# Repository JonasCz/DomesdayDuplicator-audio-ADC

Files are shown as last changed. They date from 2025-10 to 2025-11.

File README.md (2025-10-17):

# An experiment to add an audio ADC to the Domesday Duplicator (DdD)

An extension to the DdD to to add synced baseband audio support, with the DdD capture app writing it as a separate WAV file. Both PCM1802 (common module from china or custom board), or using the built-in adc128s102 that is already integrated on the DE0-nano board. PCM1802 has better quality, integrated ADC notably has a high noise floor at -40dB.

## Setup:

### You can use either:

**Custom board**: I designed a custom board, which has RCAs for both the PCM 1802, and the integrated adc128s102, allowing to use 4 channels at the same time if desired. Has better power regulator than PCM1802 modules (maybe lower noise), has a DIP switch for -10dB input level if needed.

This currently has some errors, notably the connectior is flipped so it doesn't fit as intended, and requires one small bodge for the dout output buffer (output enable needs to be low, not high). I have a few spare (pre-bodged and soldered, with RCAs once they arrive), contact @Doohickey in Domesday86 discord, for around €15 + cheap shipping in europe. I'll maybe make a fixed version later.

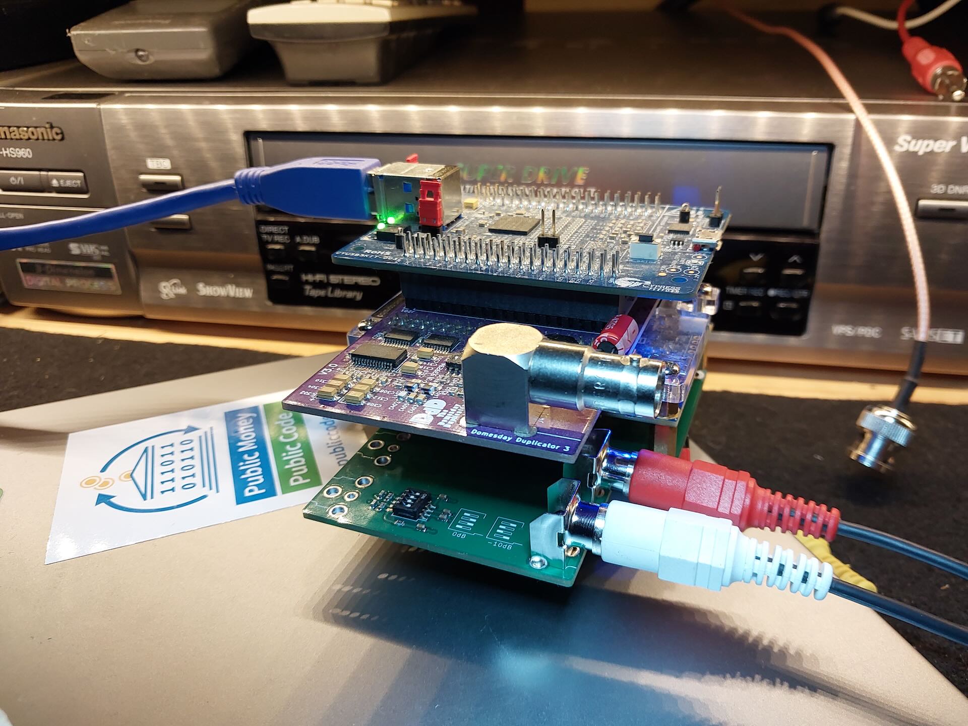
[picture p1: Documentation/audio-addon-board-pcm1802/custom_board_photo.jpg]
custom board photo


**PCM1802 module**:

You can also use the low cost PCM1802 module. Connect with jumper wires, diagram:

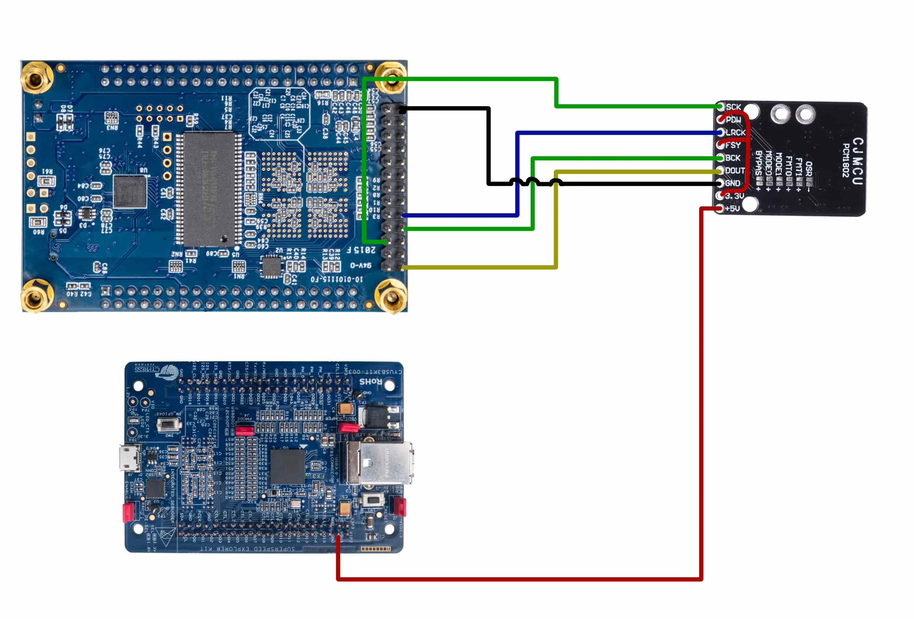
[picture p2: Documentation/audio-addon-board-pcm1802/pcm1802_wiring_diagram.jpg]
PCM1802 module connection diagram


Wires between pcm1802 and DdD should be as short as possible. You don't need to solder any of the fmt/mode/osr/bypass. Make sure the 3.3v on your module is working (3.3v is present), 3.3v needs to be connected to the pdw and fsy pins on the module. Connect lin/rin/gnd on the module to your audio source.

**adc128s102**:

Can be used with just some resistors and capacitors:

Resistors: any value between 1k and 10k works. Capacitor 1-10uF works. All capacitors and resistors need to be the same.

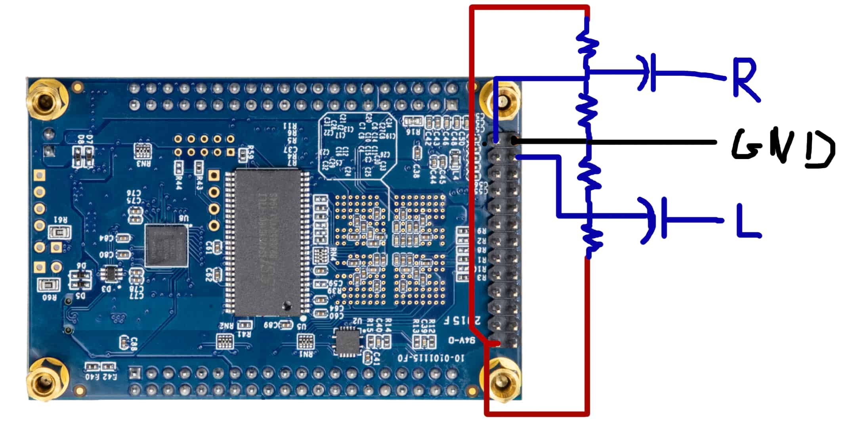
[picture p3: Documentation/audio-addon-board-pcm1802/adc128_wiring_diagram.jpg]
adc128s102


Can be used together with PCM1802 for 4 channels.

## Firmware:

You'll need to flash the firmware of the deo-nano, using the same process as for the initial flash. (firmware file in releases section). Note that there's no backward compatiblity, both the firmware and application need to be from this repository. Firmware from this repository won't work with old application either.

## Application:

Set your audio source in the application settings, then start capturing. It will write a wav file in the same location as the RF data, and show some statistics for the audio. The application is missing the logo in the UI because I couldn't get it to work, it's not intentionally removed :-)

(original readme follows)

# Domesday Duplicator (DdD)

Please see the [Project Wiki](https://github.com/simoninns/DomesdayDuplicator/wiki) for details of the project and for access to the project documentation.



The Domesday Duplicator is a LaserDisc capture focused, USB 3.0 based DAQ capable of 40 million samples per second acquisition of analogue RF data at 10-bits resolution, the data being in generic PCM style stream format is ready for [FLAC compression](https://github.com/oyvindln/vhs-decode/wiki/RF-Compression-&-Decompression-Guide) or direct use with a wide range of decoders.

Capture is via a easy to use GUI capture application.



# The Decode Family 

The samples the DdD capture can be used with the family of decoders that make the FM RF Archival workflow ready to use today.

[LaserDisc Decode](https://github.com/happycube/ld-decode) / [VHS-Decode (Videotape)](https://github.com/oyvindln/vhs-decode/wiki/) / [CVBS (Composite) Decode](CVBS-Composite-Decode) / [HiFi Decode](HiFi-Decode) / [RTLSDR HiFi Decode](RTLSDR) / [MUSE-Decode](https://bitbucket.org/staffanulfberg/ldaudio/src/master/musecpp/) / [CD-Decode](https://github.com/happycube/cd-decode) / [FL2K TBC Player](TBC-To-Analogue)

# 3D Printed Case 

The DomesDay Duplicator also has a [3D models](https://github.com/simoninns/DomesdayDuplicator-Case) and ready to use data for producing 3D printed cases, to protect from dust or line with copper tape for affordable EMI shielding for example.



## Authors

Domesday Duplicator was written & designed by [Simon Inns](https://github.com/simoninns).

Current documentation & fabrication is maintained by [Harry Munday](https://github.com/harrypm). 

## Licences

- [Software License - (Creative Commons BY-SA 4.0)](https://github.com/simoninns/DomesdayDuplicator/blob/master/LICENSE)
- [Hardware License - (GPLv3)](https://creativecommons.org/licenses/by-sa/4.0/)

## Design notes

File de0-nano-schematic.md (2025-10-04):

Of course, here is a detailed description of the Terasic DE0-Nano board's schematics, with a breakdown of each component, its pins, and their connections. 

 ### **1. Main Components and System Overview** 

 The Terasic DE0-Nano is a compact development board centered around an Altera Cyclone IV EP4CE22F17C6N FPGA. The board is designed for a wide array of applications, from educational purposes to embedded systems development. Key components on the board include: 

 *   **FPGA:** Altera Cyclone IV EP4CE22F17C6N with 22,320 logic elements. 
 *   **SDRAM:** 32MB of SDRAM for data storage. 
 *   **A/D Converter:** An 8-channel, 12-bit Analog-to-Digital Converter. 
 *   **Accelerometer:** A 3-axis digital accelerometer. 
 *   **I/O:** User LEDs, push-buttons, DIP switches, and expansion headers. 

 ### **2. Component Details and Pin Connections** 

 Below is a comprehensive list of the components, their pin names, numbers, and their connections as depicted in the schematics. 

 #### **2.1. Altera Cyclone IV FPGA (U1)** 

 The heart of the DE0-Nano board is the Cyclone IV FPGA. The following sections detail the pin connections for the various banks of the FPGA. 

 **Bank 1:** 
 *   **Pin B1 (DQS2L/CQ3L,CDPCLK0):** Connected to LED6. 
 *   **Pin C2 (DIFFIO_L3p):** Connected to DRAM_WE_N. 
 *   **Pin D1 (DIFFIO_L3n):** Connected to LED4. 
 *   **Pin F2 (DIFFIO_L4n):** Connected to I2C_SCLK. 
 *   **Pin F1 (DIFFIO_L5p):** Connected to I2C_SDAT. 
 *   **Pin G2 (DIFFIO_L5n):** Connected to DRAM_DQ0. 
 *   **Pin G1 (DIFFIO_L6p/DQS0L/CQ1L,DPCLK0):** Connected to DRAM_DQ1. 
 *   **Pin G5 (IO1_0):** Connected to G_SENSOR_CS_N. 
 *   **Pin F3 (IO/VREFB1N0):** Connected to LED5. 
 *   **Pin E1 (CLK1/DIFFCLK_0n):** Connected to KEY1. 

 **Bank 2:** 
 *   **Pin L4 (RUP1/DQ1L):** Connected to DRAM_ADDR8. 
 *   **Pin K5 (RDN1/DQ1L):** Connected to DRAM_DQ3. 
 *   **Pin R1 (IO/VREFB2N0):** Connected to DRAM_ADDR12. 
 *   **Pin L3 (CLK3/DIFFCLK_1n):** Connected to LED7 and G_SENSOR_INT. 

 **Bank 3:** 
 *   **Pin N3 (DIFFIO_B1p):** Connected to DRAM_DQ14. 
 *   **Pin P3 (DIFFIO_B1n/DM3B/BWS#3B):** Connected to DRAM_DQ13. 
 *   **Pin R3 (DIFFIO_B2p/DQ3B):** Connected to DRAM_DQ11. 
 *   **Pin T3 (DIFFIO_B2n):** Connected to DRAM_DQ10. 
 *   **Pin N5 (DIFFIO_B4p/DQ3B):** Connected to DRAM_ADDR1. 
 *   **Pin N6 (DIFFIO_B4n/DQ3B):** Connected to DRAM_ADDR2. 
 *   **Pin M7 (DIFFIO_B5p/DQS3B/CQ3B#,DPCLK2):** Connected to DRAM_BA0. 
 *   **Pin R5 (DIFFIO_B5n/DQ3B):** Connected to DRAM_DQ12. 
 *   **Pin T5 (DIFFIO_B6p/DQ3B):** Connected to DRAM_DQM1. 
 *   **Pin R6 (DIFFIO_B6n):** Connected to DRAM_DQM0. 
 *   **Pin T6 (DIFFIO_B7p/DQ3B):** Connected to DRAM_ADDR7. 
 *   **Pin R7 (DIFFIO_B7n):** Connected to DRAM_DQ7. 
 *   **Pin T7 (DIFFIO_B8p/DQ3B):** Connected to DRAM_ADDR5. 
 *   **Pin L8 (DIFFIO_B8n/DQS5B/CQ5B#,DPCLK3):** Connected to DRAM_DQ2. 
 *   **Pin M8 (DIFFIO_B9n/DQ3B):** Connected to DRAM_ADDR3. 
 *   **Pin N8 (DIFFIO_B10n/DM5B/BWS#5B):** Connected to DRAM_ADDR6. 
 *   **Pin P8 (DIFFIO_B11p/DQ5B):** Connected to DRAM_ADDR4. 
 *   **Pin T2 (IO3_0/DQS1B/CQ1B#,CDPCLK2):** Connected to DRAM_DQ9. 
 *   **Pin M6 (IO3_1/DQ3B):** Connected to DRAM_BA1. 
 *   **Pin L7 (IO3_2/DQ3B):** Connected to DRAM_CKE. 
 *   **Pin P6 (IO/VREFB3N0):** Connected to DRAM_CS_N. 
 *   **Pin R4 (PLL1_CLKOUTp):** Connected to DRAM_CLK. 
 *   **Pin T4 (PLL1_CLKOUTn):** Connected to DRAM_DQ8. 
 *   **Pin R8 (CLK15/DIFFCLK_6p):** Connected to CLOCK_50. 
 *   **Pin T8 (CLK14/DIFFCLK_6n):** Connected to SW1. 

 **Bank 4:** 
 *   **Pin N9 (DIFFIO_B14n/DQ5B):** Connected to GPIO_114. 
 *   **Pin R10 (DIFFIO_B16p/DQ5B):** Connected to GPIO_111. 
 *   **Pin T10 (DIFFIO_B16n/DQS4B/CQ5B,DPCLK4):** Connected to GPIO_18. 
 *   **Pin R11 (DIFFIO_B17p/DQ5B):** Connected to GPIO_19. 
 *   **Pin T11 (DIFFIO_B17n):** Connected to GPIO_17. 
 *   **Pin R12 (DIFFIO_B18p/DQ5B):** Connected to GPIO_16. 
 *   **Pin T12 (DIFFIO_B18n/DQ5B):** Connected to GPIO_15. 
 *   **Pin R13 (DIFFIO_B20p):** Connected to GPIO_14. 
 *   **Pin T13 (DIFFIO_B20n/DQ5B):** Connected to GPIO_13. 
 *   **Pin T14 (DIFFIO_B23p/DQ5B):** Connected to GPIO_12. 
 *   **Pin T15 (DIFFIO_B23n/DQS0B/CQ1B,CDPCLK3):** Connected to GPIO_11. 
 *   **Pin N12 (DIFFIO_B24p):** Connected to GPIO_112. 
 *   **Pin P9 (IO4_0/DQS2B/CQ3B,DPCLK5):** Connected to GPIO_113. 
 *   **Pin M10 (RUP2):** Connected to GPIO_128. 
 *   **Pin N11 (RDN2):** Connected to GPIO_115. 
 *   **Pin P11 (IO/VREFB4N0):** Connected to GPIO_110. 
 *   **Pin P14 (PLL4_CLKOUTp):** Connected to GPIO_125. 
 *   **Pin R14 (PLL4_CLKOUTn):** Connected to GPIO_122. 
 *   **Pin R9 (CLK13/DIFFCLK_7p):** Connected to GPIO_1_IN1. 
 *   **Pin T9 (CLK12/DIFFCLK_7n):** Connected to GPIO_1_IN0. 

 **Bank 5:** 
 *   **Pin P16 (DIFFIO_R15n/DQS3R/CQ3R#,CDPCLK4):** Connected to GPIO_121. 
 *   **Pin R16 (DIFFIO_R15p/DQ1R):** Connected to GPIO_118. 
 *   **Pin N16 (DIFFIO_R13n/DQ1R):** Connected to GPIO_123. 
 *   **Pin N15 (DIFFIO_R13p/DQ1R):** Connected to GPIO_124. 
 *   **Pin L13 (DIFFIO_R12p/DQ1R):** Connected to GPIO_129. 
 *   **Pin L16 (DIFFIO_R11n/DQ1R):** Connected to GPIO_116. 
 *   **Pin L15 (DIFFIO_R11p):** Connected to GPIO_119. 
 *   **Pin K16 (RUP3/DM1R/BWS#1R):** Connected to GPIO_117. 
 *   **Pin K15 (DIFFIO_R10n/DQ1R):** Connected to GPIO_131. 
 *   **Pin J16 (DIFFIO_R10p/DQS1R/CQ1R#,DRCLK6):** Connected to KEY0. 
 *   **Pin J15 (DIFFIO_R9n/DEV_OE):** Connected to GPIO_130. 
 *   **Pin J14 (DIFFIO_R9p/DEV_CLRn):** Connected to GPIO_133. 
 *   **Pin J13 (DIFFIO_R8n/DQ1R):** Connected to GPIO_132. 
 *   **Pin N14 (RDN3/DQ1R):** Connected to GPIO_127. 
 *   **Pin P15 (IO/VREFB5N0):** Connected to GPIO_120. 
 *   **Pin L14 (CLK6/DIFFCLK_3p):** Connected to GPIO_126. 
 *   **Pin M15 (CLK7/DIFFCLK_3n):** Connected to SW3. 
 *   **Pin M16:** Connected to GPIO_2_IN2. 

 **Bank 6:** 
 *   **Pin G16 (DIFFIO_R5n/INIT_DONE):** Connected to GPIO_211. 
 *   **Pin G15 (DIFFIO_R5p/CRC_ERROR):** Connected to GPIO_212. 
 *   **Pin F16 (DIFFIO_R4n/nCEO):** Connected to GPIO_29. 
 *   **Pin F15 (DIFFIO_R4p/CLKUSR):** Connected to GPIO_28. 
 *   **Pin C16 (DIFFIO_R1n/PADD20/DQS2R/CQ3R,CDPCLK5):** Connected to GPIO_23. 
 *   **Pin C15 (DIFFIO_R1p):** Connected to GPIO_24. 
 *   **Pin F13 (IO6_0):** Connected to GPIO_10. 
 *   **Pin B16 (IO6_2):** Connected to GPIO_21. 
 *   **Pin D16 (IO6_3/PADD23):** Connected to GPIO_25. 
 *   **Pin D15:** Connected to GPIO_26. 
 *   **Pin F14 (IO/VREFB6N0):** Connected to GPIO_210. 
 *   **Pin E15 (CLK4/DIFFCLK_2p):** Connected to GPIO_2_IN0. 
 *   **Pin E16 (CLK5/DIFFCLK_2n):** Connected to GPIO_2_IN1. 

 **Bank 7:** 
 *   **Pin C14 (DIFFIO_T24n):** Connected to GPIO_22. 
 *   **Pin D14 (DIFFIO_T24p/DQ5T):** Connected to GPIO_27. 
 *   **Pin D11 (DIFFIO_T23n):** Connected to GPIO_031. 
 *   **Pin D12 (DIFFIO_T23p/DQS0T/CQ1T,CDPCLK6):** Connected to GPIO_032. 
 *   **Pin A13 (DIFFIO_T22n):** Connected to LED1. 
 *   **Pin B13 (DIFFIO_T22p/DQ5T):** Connected to LED2. 
 *   **Pin A12 (DIFFIO_T21n/DQ5T):** Connected to GPIO_030. 
 *   **Pin B12 (DIFFIO_T21p/DQ5T):** Connected to GPIO_033. 
 *   **Pin A11 (DIFFIO_T20n/DQ5T):** Connected to LED3. 
 *   **Pin B11 (DIFFIO_T20p/PADD0/DQ5T):** Connected to GPIO_029. 
 *   **Pin A15 (DIFFIO_T19n/PADD1):** Connected to LED0. 
 *   **Pin F9 (DIFFIO_T17p/PADD4/DQS2T/CQ3T,DPCLK8):** Connected to GPIO_022. 
 *   **Pin A10 (DIFFIO_T16n/PADD5/DQ5T):** Connected to ADC_CS_N. 
 *   **Pin B10 (DIFFIO_T16p/PADD6/DQ5T):** Connected to ADC_SADDR. 
 *   **Pin C9 (DIFFIO_T15n/PADD7/DQ5T):** Connected to GPIO_024. 
 *   **Pin D9 (DIFFIO_T15p/PADD8/DM5T/BWS#5T):** Connected to GPIO_025. 
 *   **Pin E9 (DIFFIO_T13p/PADD12/DQS4T/CQ5T,DPCLK9):** Connected to GPIO_023. 
 *   **Pin E11 (RUP4):** Connected to GPIO_026. 
 *   **Pin E10 (RDN4):** Connected to GPIO_027. 
 *   **Pin C11 (IO/VREFB7N0):** Connected to GPIO_028. 
 *   **Pin B14 (PLL2_CLKOUTp):** Connected to ADC_SCLK. 
 *   **Pin A14 (PLL2_CLKOUTn):** Connected to GPIO_20. 
 *   **Pin B9 (CLK9/DIFFCLK_5p):** Connected to SW2. 
 *   **Pin A9 (CLK8/DIFFCLK_5n):** Connected to ADC_SDAT. 

 **Bank 8:** 
 *   **Pin D8 (DIFFIO_T11p/PADD17/DQS5T/CQ5T#,DPCLK10):** Connected to GPIO_016. 
 *   **Pin E7 (DIFFIO_T10n/DATA2/DQ3T):** Connected to GPIO_019. 
 *   **Pin D5 (DIFFIO_T10p/DATA3):** Connected to GPIO_018. 
 *   **Pin B3 (DIFFIO_T9n/PADD18/DQ3T):** Connected to GPIO_09. 
 *   **Pin C6 (DIFFIO_T9p/DATA4/DQ3T):** Connected to GPIO_04. 
 *   **Pin A4 (DIFFIO_T7n/DATA14/DQS3T/CQ3T#,DPCLK11):** Connected to GPIO_015. 
 *   **Pin D3 (DIFFIO_T7p/DATA13/DQ3T):** Connected to GPIO_07. 
 *   **Pin C3 (DIFFIO_T6p/DATA6/DQ3T):** Connected to GPIO_013. 
 *   **Pin A2 (DIFFIO_T5n/DATA7/DQ3T):** Connected to GPIO_05. 
 *   **Pin B8 (DIFFIO_T5p/DATA8/DQ3T):** Connected to GPIO_00. 
 *   **Pin A8 (DIFFIO_T4n/DATA9):** Connected to GPIO_01. 
 *   **Pin A3 (DIFFIO_T3n/DATA10/DM3T/BWS#3T):** Connected to GPIO_0_IN1. 
 *   **Pin B4 (DIFFIO_T3p/DATA11):** Connected to GPIO_0_IN0. 
 *   **Pin C5 (IO8_0/DQ3T):** Connected to GPIO_010. 
 *   **Pin C4 (IO8_1/DATA5/DQ3T):** Connected to GPIO_012. 
 *   **Pin B5 (IO8_2):** Connected to GPIO_011. 
 *   **Pin B6 (IO8_3/DATA12):** Connected to GPIO_017. 
 *   **Pin B7 (IO/VREFB8N0):** Connected to GPIO_08. 
 *   **Pin A7 (PLL3_CLKOUTp):** Connected to GPIO_02. 
 *   **Pin A6 (PLL3_CLKOUTn):** Connected to GPIO_03. 
 *   **Pin B2 (CLK11/DIFFCLK_4p):** Connected to GPIO_06. 
 *   **Pin A5 (CLK10/DIFFCLK_4n):** Connected to GPIO_0_IN_1. 

 #### **2.2. SDRAM (U5)** 

 The 32MB SDRAM is used for general-purpose data storage. 

 *   **Pins D0-D15:** Connected to the FPGA for data transfer (DRAM_DQ0-DRAM_DQ15). 
 *   **Pins A0-A12:** Connected to the FPGA for addressing (DRAM_ADDR0-DRAM_ADDR12). 
 *   **Pin CLK:** Connected to the FPGA's clock output (DRAM_CLK). 
 *   **Pin CKE:** Connected to the FPGA (DRAM_CKE). 
 *   **Pins LDQM, UDQM:** Connected to the FPGA (DRAM_DQM0, DRAM_DQM1). 
 *   **Pin nWE:** Write enable, connected to the FPGA (DRAM_WE_N). 
 *   **Pin nCAS:** Column address strobe, connected to the FPGA (DRAM_CAS_N). 
 *   **Pin nRAS:** Row address strobe, connected to the FPGA (DRAM_RAS_N). 
 *   **Pin nCS:** Chip select, connected to the FPGA (DRAM_CS_N). 
 *   **Pins BA0, BA1:** Bank address, connected to the FPGA (DRAM_BA0, DRAM_BA1). 

 #### **2.3. Digital Accelerometer (U3)** 

 The ADXL345 is a 3-axis accelerometer that communicates over an I2C interface. 

 *   **Pin SCL_SCLK:** Connected to the FPGA's I2C clock line (I2C_SCLK). 
 *   **Pin SDA_SDI_SDIO:** Connected to the FPGA's I2C data line (I2C_SDAT). 
 *   **Pin CSn:** Chip select, connected to the FPGA (G_SENSOR_CS_N). 
 *   **Pin INT1:** Interrupt 1, connected to the FPGA (G_SENSOR_INT). 

 #### **2.4. ADC (U4)** 

 The ADC128S022 is an 8-channel, 12-bit A/D converter. 

 *   **Pins IN0-IN7:** Analog input channels, connected to the 2x13 header (JP3). 
 *   **Pin CS_n:** Chip select, connected to the FPGA (ADC_CS_N). 
 *   **Pin DIN:** Data in, connected to the FPGA (ADC_SDAT). 
 *   **Pin DOUT:** Data out, connected to the FPGA (ADC_SADDR). 
 *   **Pin SCLK:** Serial clock, connected to the FPGA (ADC_SCLK). 

 #### **2.5. Headers** 

 The board includes three main headers for expansion. 

 **GPIO-0 (JP1):** 
 *   **Pins 1-40:** Provide connections to various GPIO pins of the FPGA (GPIO_00 to GPIO_033). 

 **GPIO-1 (JP2):** 
 *   **Pins 1-40:** Provide connections to various GPIO pins of the FPGA (GPIO_10 to GPIO_133). 

 **GPIO-2 (JP3 - 2x13 Header):** 
 *   **Pins 1-26:** Offer a mix of digital I/O (GPIO_20 to GPIO_212) and analog inputs (Analog_In0 to Analog_In7). 

 ### **3. User Interface and Configuration** 

 The board provides simple user interface elements for interaction and status indication. 

 *   **LEDs (LEDA-LEDG):** 8 user-programmable LEDs connected to the FPGA. 
 *   **Push-buttons (KEY0, KEY1):** Two push-buttons for user input. 
 *   **DIP Switches (SW1):** A 4-position DIP switch for configuration. 
 *   **Clock:** A 50MHz oscillator provides the main clock signal to the FPGA. 

 This detailed breakdown should provide a comprehensive understanding of the DE0-Nano's schematic and its various components and connections.

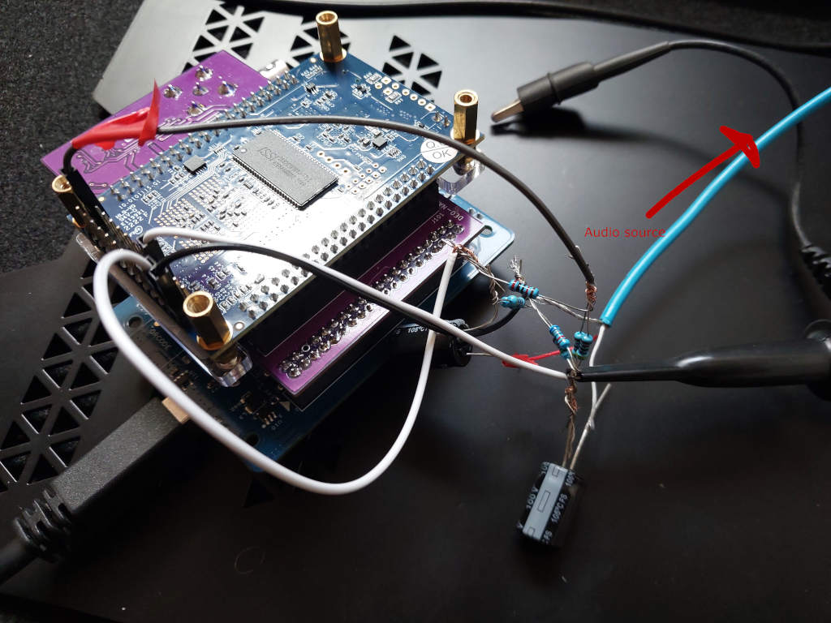
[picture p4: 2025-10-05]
DdD_with_adc.jpg

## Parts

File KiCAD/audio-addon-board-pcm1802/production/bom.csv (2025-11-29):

Designator | Footprint | Quantity | Value | LCSC Part #
C1, C10, C15, C22, C3, C5, C6, C9, CNP1 | 0603 | 9 | 10uF | C96446
C11, C13, C14, C16, C2, C7, C8, CNP2 | 0603 | 8 | 0.22uF | C21120
C12, C17, C23, C24 | 0603 | 4 | 1uF | C15849
C18, C19 | 0603 | 2 | 100pF | C14858
C20, C21 | 0603 | 2 | 4.7nF | C53987
C4 | 0603 | 1 | 1nF | C1588
D1, D2 | 0805 | 2 | LED
FB1 | 0805 | 1 | 600R@100 MHz <100 mR | C1017
J2 | PinSocket_2x13_P2.54mm_Vertical | 1 | CONN_HOST_1
JFSYNC1 | SolderJumper-2_P1.3mm_Bridged_RoundedPad1.0x1.5mm | 1 | Jumper_2_Small_Bridged
R1, R2 | 0603 | 2 | 1k | C21189
R10, R5, R6, R7 | 0603 | 4 | 22R | C23345
R11, R13, R14, R9, RA1, RA2 | 0603 | 6 | 1k | C21190
R4 | 0603 | 1 | 0R | C21189
RA3, RA4 | 0603 | 2 | 47k | C25819
SW1 | SW_DIP_SPSTx04_Slide_Copal_CHS-04B_W7.62mm_P1.27mm | 1 | SW_DIP_x04 | C319050
U1 | DB0020A-MFG | 1 | PCM1802DBR | C1520787
U2 | SO-8_S_LIT | 1 | LTC1682IS8-5 | C676404

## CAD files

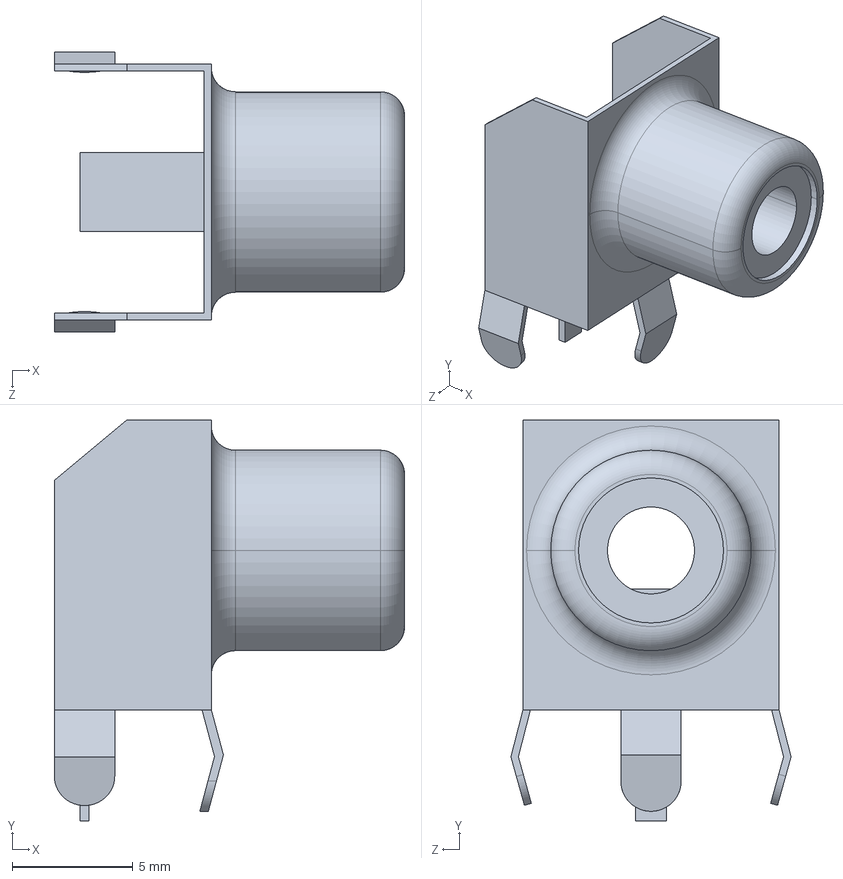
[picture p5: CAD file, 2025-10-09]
KiCAD/audio-addon-board-pcm1802/parts/Same_Sky_RCJ-011/Same_Sky_RCJ-011.step
14.5 x 16.6 x 11.6 mm

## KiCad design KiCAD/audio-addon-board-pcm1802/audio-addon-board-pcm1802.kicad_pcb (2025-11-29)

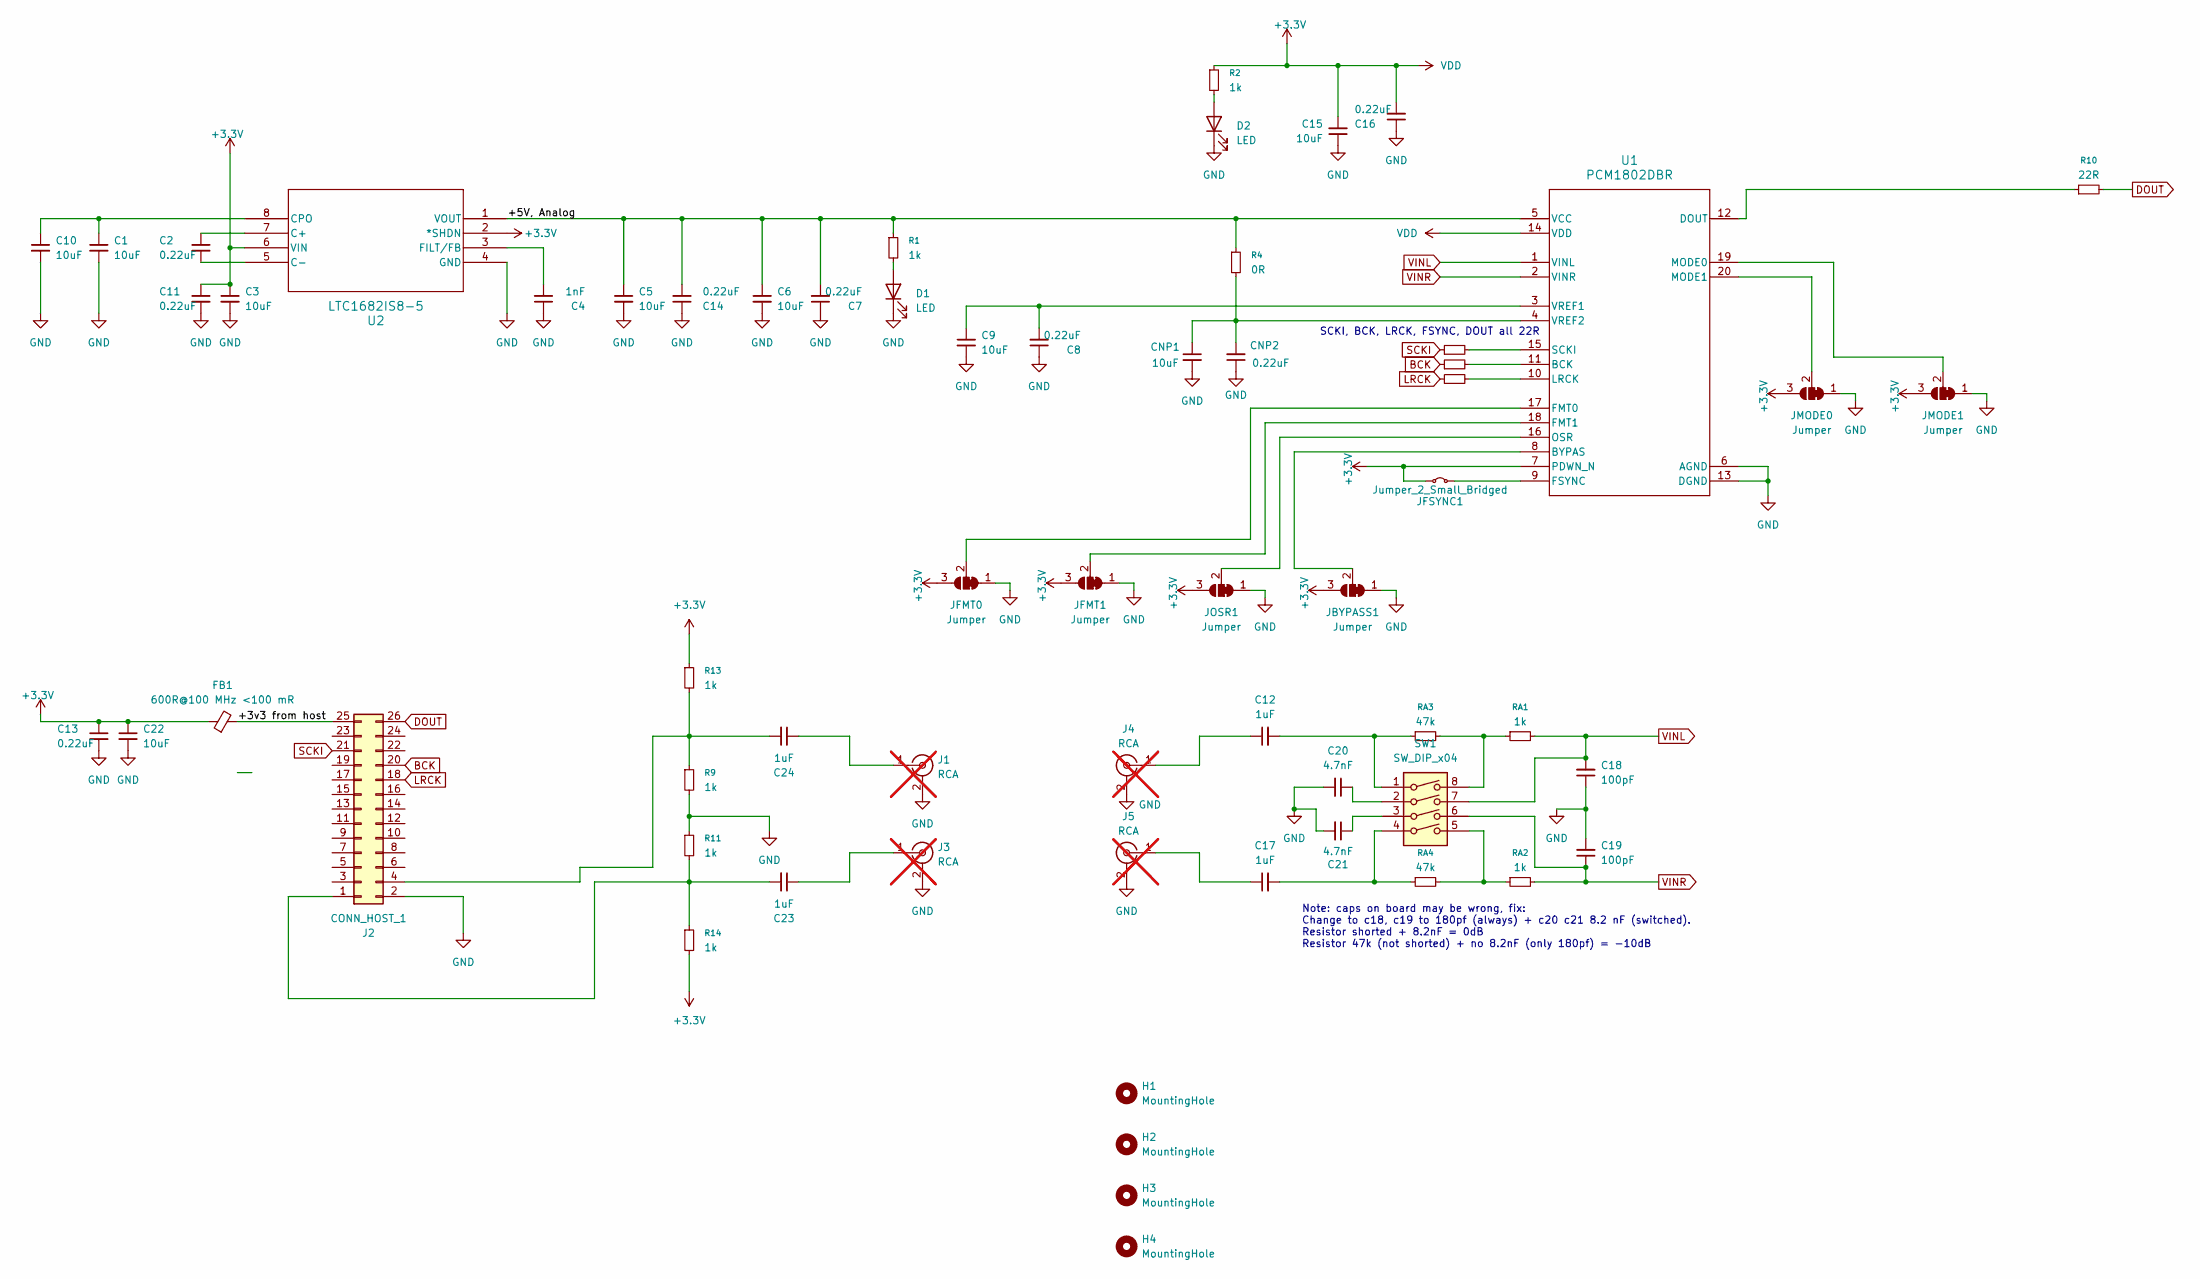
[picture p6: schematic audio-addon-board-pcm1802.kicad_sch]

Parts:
C1, C3, C5, C6, C9, C10, C15, C22: 10uF; C_0603_1608Metric; LCSC PN C96446
C2, C7, C8, C11, C13, C14, C16: 0.22uF; C_0603_1608Metric; LCSC PN C21120
C4: 1nF; C_0603_1608Metric; LCSC PN C1588
C12, C17, C23, C24: 1uF; C_0603_1608Metric; LCSC PN C15849
C18, C19: 100pF; C_0603_1608Metric; LCSC PN C14858
C20, C21: 4.7nF; C_0603_1608Metric; LCSC PN C53987
CNP1: 10uF; C_0603_1608Metric; LCSC PN C96446
CNP2: 0.22uF; C_0603_1608Metric; LCSC PN C21120
D1: LED; LED_0603_1608Metric
D2: LED; LED_0805_2012Metric
FB1: 600R@100 MHz <100 mR; L_0805_2012Metric; LCSC PN C1017
H1, H2, H3, H4: MountingHole; MountingHole_3.2mm_M3_DIN965_Pad_TopBottom
J1, J3, J4, J5: RCA; RCA-Phono_CUI-Devices_RCJ-01X_Horizontal; not fitted
J2: CONN_HOST_1; PinSocket_2x13_P2.54mm_Vertical
JBYPASS1: Jumper; SolderJumper-3_P1.3mm_Bridged12_RoundedPad1.0x1.5mm
JFMT0, JFMT1: Jumper; SolderJumper-3_P1.3mm_Bridged12_RoundedPad1.0x1.5mm
JFSYNC1: Jumper_2_Small_Bridged; SolderJumper-2_P1.3mm_Bridged_RoundedPad1.0x1.5mm
JMODE0, JMODE1: Jumper; SolderJumper-3_P1.3mm_Bridged12_RoundedPad1.0x1.5mm
JOSR1: Jumper; SolderJumper-3_P1.3mm_Bridged12_RoundedPad1.0x1.5mm
R1, R2: 1k; R_0603_1608Metric; LCSC PN C21189
R4: 0R; R_0603_1608Metric; LCSC PN C21189
R5, R6, R7, R10: 22R; R_0603_1608Metric; LCSC PN C23345
R9, R11, R13, R14: 1k; R_0603_1608Metric; LCSC PN C21190
RA1, RA2: 1k; R_0603_1608Metric; LCSC PN C21190
RA3, RA4: 47k; R_0603_1608Metric; LCSC PN C25819
SW1: SW_DIP_x04; SW_DIP_SPSTx04_Slide_Copal_CHS-04B_W7.62mm_P1.27mm; LCSC PN C319050
U1: PCM1802DBR; DB0020A-MFG; LCSC PN C1520787
U2: LTC1682IS8-5; SO-8_S_LIT; LCSC PN C676404

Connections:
+3.3V: C3.1, C11.1, C13.1, C15.2, C16.2, C22.1, FB1.1, JBYPASS1.3 (B), JFMT0.3 (B), JFMT1.3 (B), JFSYNC1.1 (A), JMODE0.3 (B), JMODE1.3 (B), JOSR1.3 (B), R2.1, R13.1, R14.2, U1.7 (PDWN_N), U1.14 (VDD), U2.2 (*SHDN), U2.6 (VIN)
/+3v3 from host: FB1.2, J2.25
/+5V, Analog: C5.1, C6.1, C7.2, C14.2, R1.1, R4.1, U1.5 (VCC), U2.1 (VOUT)
BCK: J2.20, R6.1
DOUT: J2.26, R10.2
GND: C1.2, C3.2, C4.1, C5.2, C6.2, C7.1, C8.1, C9.2, C10.2, C11.2, C13.2, C14.1, C15.1, C16.1, C18.1, C19.2, C20.2, C21.2, C22.2, CNP1.2, CNP2.1, D1.1 (K), D2.1 (K), J1.2 (Ext), J2.2, J3.2 (Ext), J4.2 (Ext), J5.2 (Ext), JBYPASS1.1 (A), JFMT0.1 (A), JFMT1.1 (A), JMODE0.1 (A), JMODE1.1 (A), JOSR1.1 (A), R9.2, R11.1, U1.6 (AGND), U1.13 (DGND), U2.4 (GND)
LRCK: J2.18, R7.1
unnamed: C12.2, RA3.1, SW1.1
unnamed: C17.2, RA4.1, SW1.4
unnamed: C20.1, SW1.2
unnamed: C21.1, SW1.3
unnamed: D1.2 (A), R1.2
unnamed: D2.2 (A), R2.2
unnamed: C24.1, J1.1 (In)
unnamed: C23.2, J2.1, R11.2, R14.1
unnamed: C24.2, J2.4, R9.1, R13.2
unnamed: C23.1, J3.1 (In)
unnamed: C12.1, J4.1 (In)
unnamed: C17.1, J5.1 (In)
unnamed: JBYPASS1.2 (C), U1.8 (BYPAS)
unnamed: JFMT0.2 (C), U1.17 (FMT0)
unnamed: JFMT1.2 (C), U1.18 (FMT1)
unnamed: JFSYNC1.2 (B), U1.9 (FSYNC)
unnamed: JMODE0.2 (C), U1.20 (MODE1)
unnamed: JMODE1.2 (C), U1.19 (MODE0)
unnamed: JOSR1.2 (C), U1.16 (OSR)
unnamed: RA1.1, RA3.2, SW1.8
unnamed: RA2.1, RA4.2, SW1.5
unnamed: R6.2, U1.11 (BCK)
unnamed: R10.1, U1.12 (DOUT)
unnamed: R7.2, U1.10 (LRCK)
unnamed: R5.2, U1.15 (SCKI)
unnamed: C8.2, C9.1, U1.3 (VREF1)
unnamed: CNP1.1, CNP2.2, R4.2, U1.4 (VREF2)
unnamed: C2.1, U2.7 (C+)
unnamed: C2.2, U2.5 (C-)
unnamed: C1.1, C10.1, U2.8 (CPO)
unnamed: C4.2, U2.3 (FILT/FB)
SCKI: J2.21, R5.1
VINL: C18.2, RA1.2, SW1.7, U1.1 (VINL)
VINR: C19.1, RA2.2, SW1.6, U1.2 (VINR)

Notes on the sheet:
Note: caps on board may be wrong, fix: Change to c18, c19 to 180pf (always) + c20 c21 8.2 nF (switched). Resistor shorted + 8.2nF = 0dB Resistor 47k (not shorted) + no 8.2nF (only 180pf) = -10dB
SCKI, BCK, LRCK, FSYNC, DOUT all 22R

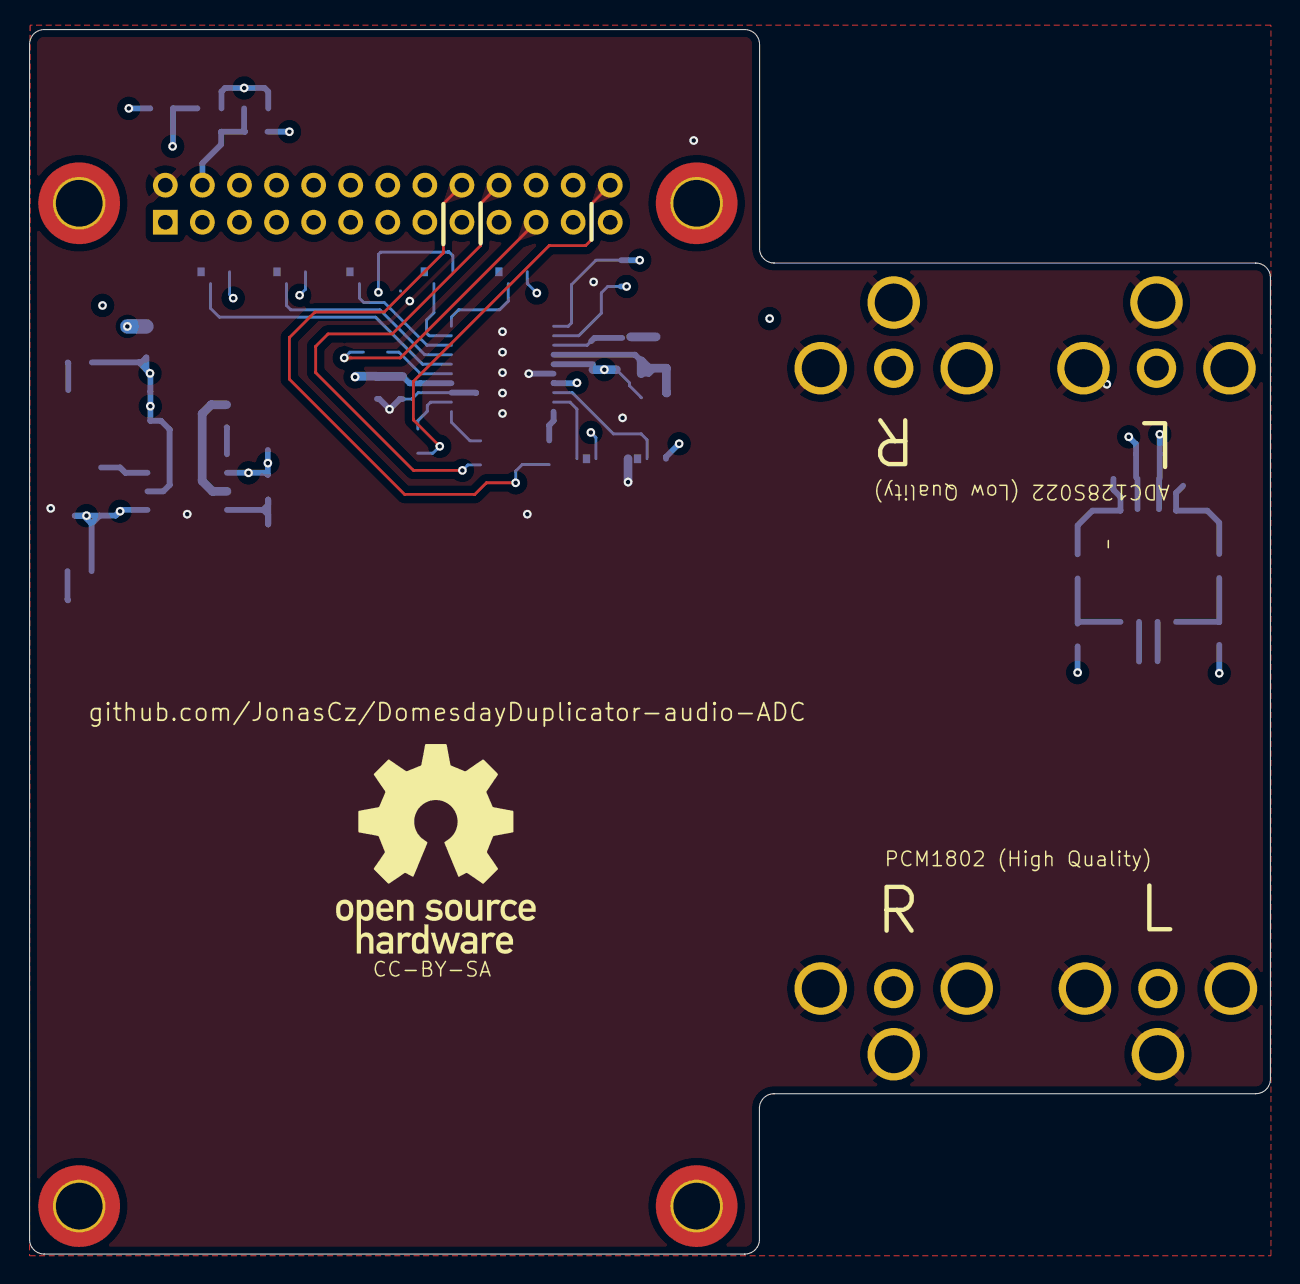
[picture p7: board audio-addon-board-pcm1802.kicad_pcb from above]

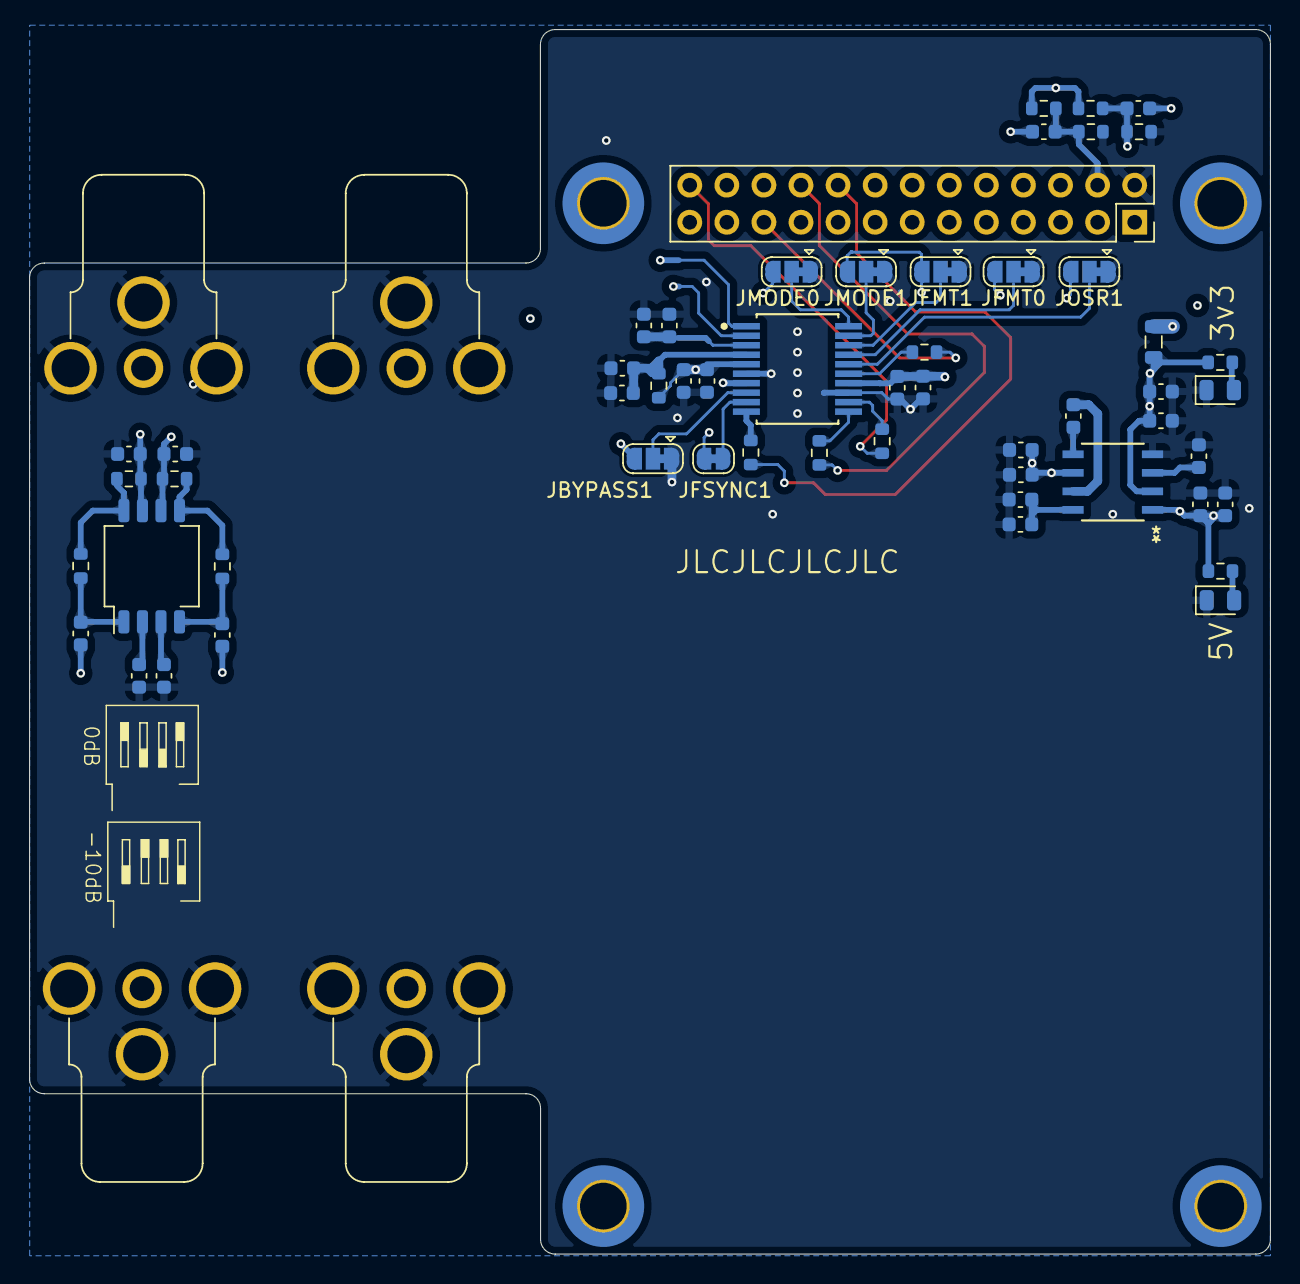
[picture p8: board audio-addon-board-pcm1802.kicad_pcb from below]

Board: 4 copper layers, 85.0 x 83.9 mm, 63 parts (59 on the bottom side), 41 nets.

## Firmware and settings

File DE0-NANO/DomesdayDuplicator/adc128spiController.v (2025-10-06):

module adc128spiController (
// System clock and reset
input  wire        clk_40MHz,
input  wire        nReset,

// SPI interface to ADC128S022
output reg         spi_cs_n,     // Chip select (active low)
output reg         spi_sclk,     // Serial clock (2.5 MHz)
output reg         spi_din,      // Data to ADC (channel select)
input  wire        spi_dout,     // Data from ADC (conversion result)

// Audio output (to dataGenerator)
output reg  [11:0] audio_left,
output reg  [11:0] audio_right,
output reg         audio_ready   // Pulses once per L+R pair

);

// 40 MHz -> 2.5 MHz SCLK
// Tick every 8 clocks, drive SCLK edges on ticks
reg [2:0] clk_div;
wire sclk_tick = (clk_div == 3'd7);

always @(posedge clk_40MHz or negedge nReset) begin
	if (!nReset)
		clk_div <= 3'd0;
	else
		clk_div <= clk_div + 3'd1; // wraps at 8
end

// FSM
localparam ST_IDLE  = 2'd0;
localparam ST_PREP  = 2'd1; // CS low, SCLK low, DIN preloaded, wait one tick
localparam ST_SHIFT = 2'd2; // 16 SCLK rising edges

reg [1:0]  state;

// Control word (MSB-first): [7:6]=00, [5:3]=ADD2:ADD0, [2:0]=000
reg [7:0] ctrl;

// Rising-edge counter (0..15 where 1..16 are rising edges in a frame)
reg [4:0] rise_count;

// Shift register and final latched sample
reg [11:0] shift_reg;
reg [11:0] sample_word;

// Channel pipeline: sample you get now belongs to prev_channel;
// we set up next_channel for the next frame.
reg [2:0] prev_channel;
reg [2:0] next_channel;

always @(posedge clk_40MHz or negedge nReset) begin
	if (!nReset) begin
		spi_cs_n     <= 1'b1;
		spi_sclk     <= 1'b0;
		spi_din      <= 1'b0;

		audio_left   <= 12'd0;
		audio_right  <= 12'd0;
		audio_ready  <= 1'b0;

		state        <= ST_IDLE;
		rise_count   <= 5'd0;
		shift_reg    <= 12'd0;
		sample_word  <= 12'd0;

		ctrl         <= 8'h00;
		prev_channel <= 3'd0; // ADC defaults to CH0 after reset
		next_channel <= 3'd0; // Start by requesting CH0
	end else begin
		audio_ready <= 1'b0; // default

		case (state)
			ST_IDLE: begin
				// Compose control word for upcoming frame
				ctrl       <= {2'b00, next_channel, 3'b000};

				// Assert CS, hold SCLK low, preset DIN to first (MSB) bit
				spi_cs_n   <= 1'b0;
				spi_sclk   <= 1'b0;
				spi_din    <= ctrl[7];
				rise_count <= 5'd0;
				shift_reg  <= 12'd0;

				// Hold DIN for at least one tick before first rising edge
				state <= ST_PREP;
			end

			ST_PREP: begin
				// Wait exactly one sclk_tick so DIN is stable before 1st rising edge
				if (sclk_tick) begin
					state <= ST_SHIFT;
				end
			end

			ST_SHIFT: begin
				if (sclk_tick) begin
					if (spi_sclk == 1'b0) begin
						// Rising edge is about to be generated (we set spi_sclk=1 below)
						// ADC latches DIN on this rising edge; we sample DOUT here.
						// Count rising edges 1..16
						// We use the old value of rise_count for decisions and then increment.
						// Bits from DOUT are valid to sample on rising edges 5..16,
						// which corresponds to rise_count values 4..15 before increment.
						if (rise_count >= 5'd4 && rise_count <= 5'd15) begin
							shift_reg <= {shift_reg[10:0], spi_dout};
							if (rise_count == 5'd15) begin
								sample_word <= {shift_reg[10:0], spi_dout};
							end
						end

						// Shift the control word AFTER the ADC latched current bit
						ctrl <= {ctrl[6:0], 1'b0};

						// Advance rising edge count
						rise_count <= rise_count + 5'd1;

						// If that was the 16th rising edge (rise_count was 15), frame is done
						if (rise_count == 5'd15) begin
							// Store the sample according to the previous channel
							case (prev_channel)
								3'd0: audio_left  <= sample_word; // CH0
								3'd1: audio_right <= sample_word; // CH1
								default: ; // ignore other channels
							endcase

							// Pulse 'audio_ready' after CH1 completes (once per L+R pair)
							if (prev_channel == 3'd1) begin
								audio_ready <= 1'b1;
							end

							// Pipeline channel selection
							prev_channel <= next_channel;
							next_channel <= (next_channel == 3'd0) ? 3'd1 : 3'd0;

							// End frame: deassert CS, force SCLK low, go idle
							spi_cs_n <= 1'b1;
							spi_sclk <= 1'b0;
							state    <= ST_IDLE;
						end else begin
							// Normal rising edge: drive SCLK high
							spi_sclk <= 1'b1;
						end
					end else begin
						// Falling edge: ADC changes DOUT shortly after this,
						// so we set up DIN here (stable for next rising edge)
						spi_din  <= ctrl[7];
						spi_sclk <= 1'b0;
					end
				end
			end

			default: state <= ST_IDLE;
		endcase
	end
end

endmodule

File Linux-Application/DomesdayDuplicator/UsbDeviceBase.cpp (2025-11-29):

#include "UsbDeviceBase.h"
#ifdef _WIN32
#include <memoryapi.h>
#else
#include <sched.h>
#include <sys/mman.h>
#endif
#include <iostream>
#include <thread>
#include <functional>
#include <cassert>
#include <cmath>

//----------------------------------------------------------------------------------------------------------------------
// Constructors
//----------------------------------------------------------------------------------------------------------------------
UsbDeviceBase::UsbDeviceBase(const ILogger& log)
:log(log)
{ }

//----------------------------------------------------------------------------------------------------------------------
UsbDeviceBase::~UsbDeviceBase()
{ }

//----------------------------------------------------------------------------------------------------------------------
bool UsbDeviceBase::Initialize(uint16_t vendorId, uint16_t productId)
{
    // Attempt to retrieve the initial process working set allocation
#ifdef _WIN32
    BOOL getProcessWorkingSetSizeReturn = GetProcessWorkingSetSize(GetCurrentProcess(), &originalProcessMinimumWorkingSetSizeInBytes, &originalProcessMaximumWorkingSetSizeInBytes);
    if (getProcessWorkingSetSizeReturn == 0)
    {
        DWORD lastError = GetLastError();
        Log().Error("GetProcessWorkingSetSize failed with error code {0}", lastError);
        return false;
    }
#endif
    return true;
}

//----------------------------------------------------------------------------------------------------------------------
// Log methods
//----------------------------------------------------------------------------------------------------------------------
const ILogger& UsbDeviceBase::Log() const
{
    return log;
}

//----------------------------------------------------------------------------------------------------------------------
// Device methods
//----------------------------------------------------------------------------------------------------------------------
void UsbDeviceBase::SendConfigurationCommand(const std::string& preferredDevicePath, bool testMode)
{
    // Bit 0: Set test mode
    // Bit 1: Unused
    // Bit 2: Unused
    // Bit 3: Unused
    // Bit 4: Unused
    uint16_t configurationFlags = 0b00000;
    configurationFlags |= (testMode ? 0b00001 : 0b00000);
    SendVendorSpecificCommand(preferredDevicePath, 0xB6, configurationFlags);
}

//----------------------------------------------------------------------------------------------------------------------
// Capture methods
//----------------------------------------------------------------------------------------------------------------------
bool UsbDeviceBase::StartCapture(const std::filesystem::path& filePath, CaptureFormat format, AudioSource audioSource, const std::string& preferredDevicePath, bool isTestMode, bool useSmallUsbTransfers, bool useAsyncFileIo, size_t usbTransferQueueSizeInBytes, size_t diskBufferQueueSizeInBytes, bool stopOnDroppedSamples)
{
    // If we're already performing a capture, abort any further processing.
    if (transferInProgress)
    {
        Log().Error("StartCapture(): Capture was currently in progress");
        return false;
    }

    // Attempt to connect to the target device
    if (!ConnectToDevice(preferredDevicePath))
    {
        Log().Error("StartCapture(): Failed to connect to the target device");
        captureResult = TransferResult::ConnectionFailure;
        return false;
    }

    // Flag whether we should be using asynchronous IO (Windows only)
#ifdef _WIN32
    useWindowsOverlappedFileIo = useAsyncFileIo;
#endif

    // Attempt to create/open the output file
#ifdef _WIN32
    if (useWindowsOverlappedFileIo)
    {
        windowsCaptureOutputFileHandle = CreateFileW(filePath.wstring().c_str(), GENERIC_WRITE, FILE_SHARE_READ, NULL, CREATE_ALWAYS, FILE_FLAG_SEQUENTIAL_SCAN | FILE_FLAG_WRITE_THROUGH | FILE_FLAG_OVERLAPPED, NULL);
        if (windowsCaptureOutputFileHandle == INVALID_HANDLE_VALUE)
        {
            DWORD lastError = GetLastError();
            Log().Error("CreateFileW returned {0} with error code {1}.", windowsCaptureOutputFileHandle, lastError);
            captureResult = TransferResult::FileCreationError;
            return false;
        }
    }
    else
    {
#endif
        captureOutputFile.clear();
        captureOutputFile.rdbuf()->pubsetbuf(0, 0);
        captureOutputFile.open(filePath, std::ios::out | std::ios::trunc | std::ios::binary);
        if (!captureOutputFile.is_open())
        {
            Log().Error("StartCapture(): Failed to create the output file at path {0}", filePath);
            captureResult = TransferResult::FileCreationError;
            return false;
        }
#ifdef _WIN32
    }
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

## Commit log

2025-10-04 inital on-board audio ADC implementation (LLM)
2025-10-05 fixes, comment out the seq number for now
    [UsbDeviceBase.cpp]
2025-10-06 fix to have same ADC channels always
    [adc128spiController.v]
2025-10-07 add intial PCB progress
    [audio-addon-board-pcm1802.kicad_pcb, audio-addon-board-pcm1802.kicad_sch]
2025-10-07 working on layout
    [audio-addon-board-pcm1802.kicad_pcb, audio-addon-board-pcm1802.kicad_sch]
2025-10-09 working on layout (2025-10-09 sent to jlc)
    [Same_Sky_RCJ-011.step, audio-addon-board-pcm1802-rounded.kicad_pcb, audio-addon-board-pcm1802.kicad_sch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]
2025-10-15 more work on the software for audio capture
    [configuration.h]
2025-10-16 add note to fix cap values
    [audio-addon-board-pcm1802.kicad_sch]
2025-10-20 update schematic
    [audio-addon-board-pcm1802.kicad_pcb, audio-addon-board-pcm1802.kicad_sch]
2025-10-23 initial board fixes
    [audio-addon-board-pcm1802.kicad_pcb]
2025-10-27 board fixes, finished
    [audio-addon-board-pcm1802.kicad_pcb, audio-addon-board-pcm1802.kicad_sch]
2025-10-28 board fixes
    [audio-addon-board-pcm1802.kicad_pcb, audio-addon-board-pcm1802.kicad_sch]
2025-11-17 update board photo
2025-11-17 update board
    [audio-addon-board-pcm1802-rounded.kicad_pcb, audio-addon-board-pcm1802.kicad_pcb, audio-addon-board-pcm1802.kicad_sch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]
2025-11-29 ignore sync loss
    [configuration.h]
2025-12-12 Add WinUSB toggle functionality to configuration dialog
    [configurationdialog.h]

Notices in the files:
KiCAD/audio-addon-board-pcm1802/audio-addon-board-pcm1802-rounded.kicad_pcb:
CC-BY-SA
